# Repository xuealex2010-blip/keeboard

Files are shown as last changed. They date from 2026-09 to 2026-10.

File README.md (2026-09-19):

# Keeboard
Hack Club Sponsored DIY Keyboard

Hey, thanks for checking this out, this is my own attempt at creating a DIY 75% Low Profile Mechanical Keyboard.

More details about the process can be found in the Journal Logs.

## CAD
https://cad.onshape.com/documents/ea891d14d2da634eb3b1d96d/w/6142ce2636ba78c1d8d6bd10/e/d20a11642471013c1442f2cf



I decided to go for an affordable green keycap set since I love the color and its one of the cheapest low profile options.



I used heat set inserts and square nuts to hold the case together, I think that this is better than a large 3D print as its designed to be printed at that size. I used only 2 screw lengths which kept the hardware costs low.

## KiCad
https://kicanvas.org/?repo=https%3A%2F%2Fgithub.com%2Fxuealex2010-blip%2Fkeeboard%2Ftree%2Fmain%2FPCB

### Schematic



The schematic final design uses a very basic layout of all the switches. 
I used a generic connector instead of the PiPico symbol to manage the GPIO positions better. I made sure to double check with the official pinouts.

### PCB



This PCB uses a lot more vias than expected, this was to separate the long traces better, and improve ground fill space.

I also made special edge cuts in the PCB, this is because the low profile layout stabilizers drop deep below the plate that it would collide with the PCB if not so.

## Reflection

This was a fun journey, I learned a lot about keyboards, PCB design, and even some more cad skills in specific use cases.
I wanted to do this project because I thought it would be nice to get a cool mechanical keyboard. This still remains so, but I also realize how much I was able to learn. I also think that the this keyboard is much more than a mechanical keyboard, since it has sentimental value since, well I made it. 
I would like to thank Hack Club for showing me this opportunity, even if I don't get to build it, I have learned a lot.

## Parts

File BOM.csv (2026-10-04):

Vendor | Item | Qty Incl. | Qty Used | Cost (shipping incl) | Link
Aliexpress | Keyswitches | 90 | 82 | $34.15 | https://www.aliexpress.us/item/3256812101477500.html?mp=1&_randl_shipto=US
Aliexpress | Keycaps | 143 | 82 | $19.08 | https://www.aliexpress.us/item/3256804654045406.html?mp=1
Aliexpress | Stabilizers | 5 | 4 | $13.35 | https://www.aliexpress.us/item/3256805109925838.html?mp=1
Aliexpress | EC11 Encoder | 5 | 1 | $2.83 | https://www.aliexpress.us/item/3256801777806102.html?mp=1
Aliexpress | SOD-123 Diode | 500 | 90 | $5.33 | https://www.aliexpress.us/item/3256812429587907.html?curPageLogUid=SeGesrcKaOci
Aliexpress | Pico 2 | 1 | 1 | $2.23 | https://www.aliexpress.us/item/3256805430865417.html?mp=1
Aliexpress | Heat Inserts | 100 | 18 | $2.25 | https://www.aliexpress.us/item/3256807466816961.html?mp=1&_randl_shipto=US
Aliexpress | LP Screws | 40 | 4 | $7.55 | https://www.aliexpress.us/item/3256812814549829.html?mp=1
Aliexpress | CS Screws | 50 | 8 | $3.67 | https://www.aliexpress.us/item/3256805377257558.html?mp=1
Aliexpress | Square Nuts | 40 | 4 | $5.60 | https://www.aliexpress.us/item/3256804067194395.html?mp=1
Aliexpress | Poron Foam | 20 | 8 | $5.74 | https://www.aliexpress.us/item/3256805377257558.html?mp=1
Aliexpress | Rubber Feet | 100 | 4 | $6.03 | https://www.aliexpress.us/item/3256812503581701.html?mp=1
JLCPCB | PCB | 5 | 1 | $36.46

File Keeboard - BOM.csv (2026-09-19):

Item | Qty Incl. | Qty Used
Keyswitches | 90 | 82
Keycaps | 143 | 82
Stabilizers | 5 | 4
EC11 Encoder | 5 | 1
SOD-123 Diode | 500 | 90
Pico 2 | 1 | 1
Heat Inserts | 100 | 18
LP Screws | 40 | 4
CS Screws | 50 | 8
Square Nuts | 40 | 4
Poron Foam | 20 | 8
Rubber Feet | 100 | 4
PCB | 5 | 1

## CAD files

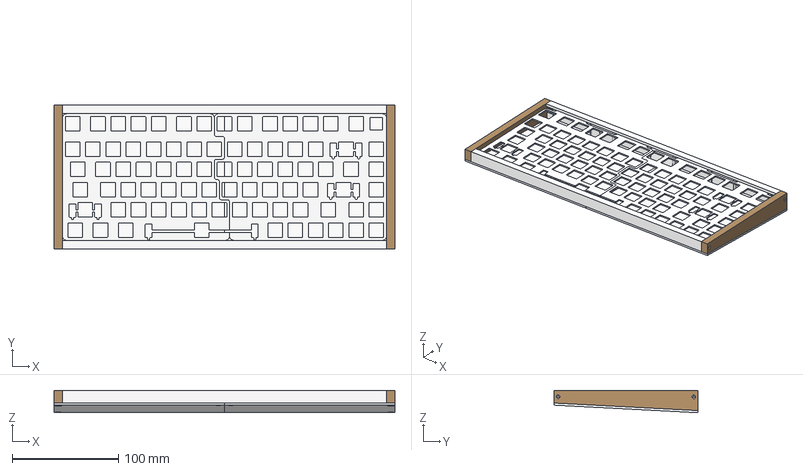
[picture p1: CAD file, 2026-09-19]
3D Print Case/Case Assembly (not for printing).step
320.8 x 135.1 x 21.1 mm
BottomCover-L
Bar S x 2
BottomCover-R
Bar L x 2
Plate-R
Plate-L

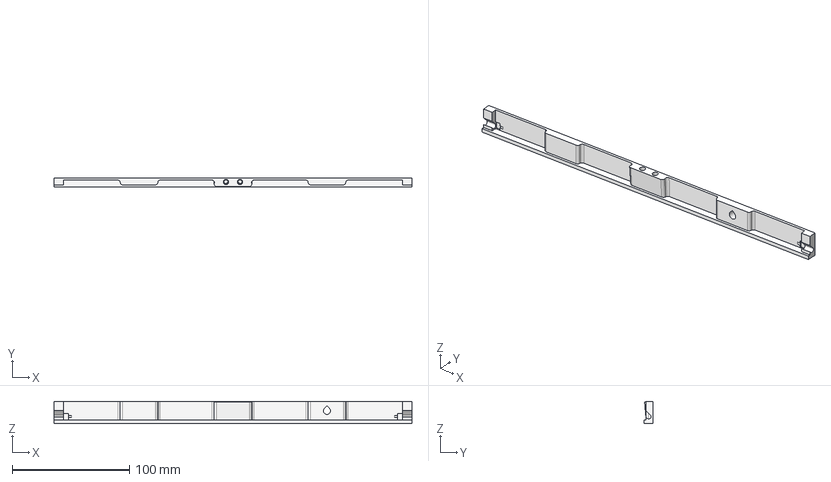
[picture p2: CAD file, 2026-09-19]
3D Print Case/Bar-Back.step
304.8 x 8.00 x 19.0 mm

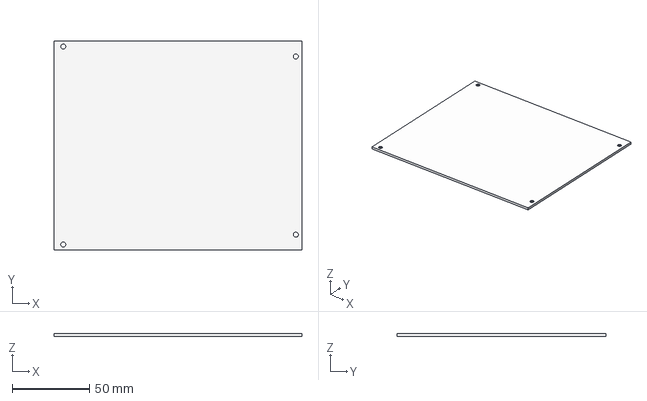
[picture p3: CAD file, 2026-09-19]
3D Print Case/BottomCover-R.step
160.4 x 135.3 x 2.00 mm

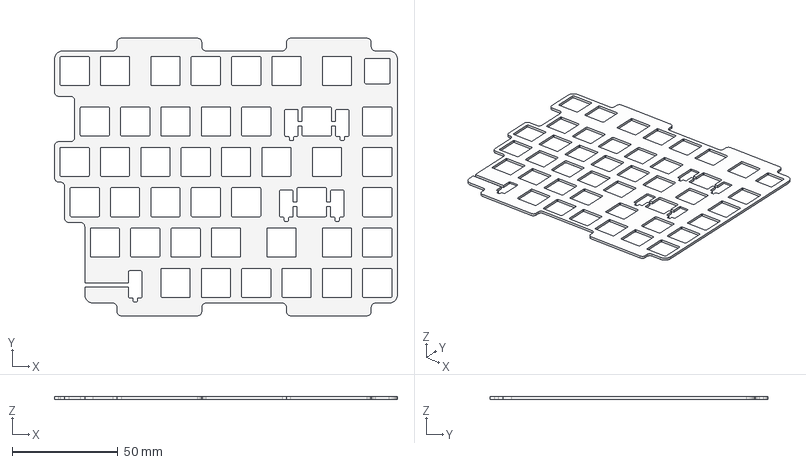
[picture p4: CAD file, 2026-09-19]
3D Print Case/Plate-R.step
161.9 x 131.1 x 1.40 mm

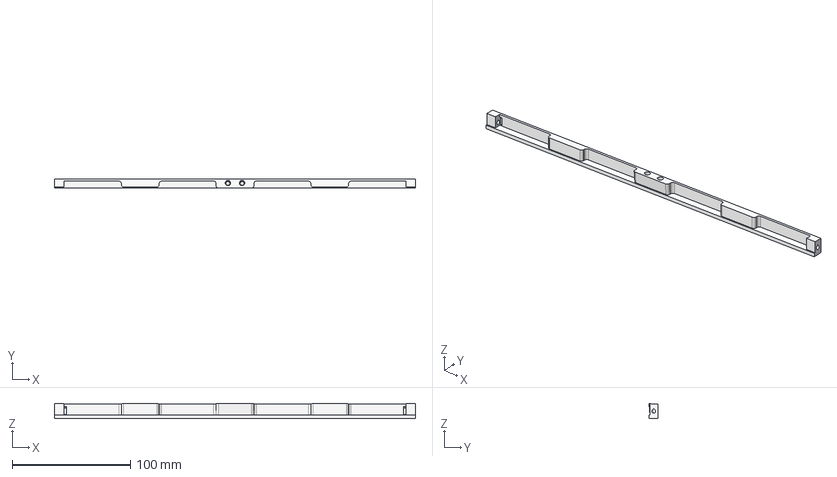
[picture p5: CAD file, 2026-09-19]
3D Print Case/Bar-Front.step
304.8 x 8.00 x 12.4 mm

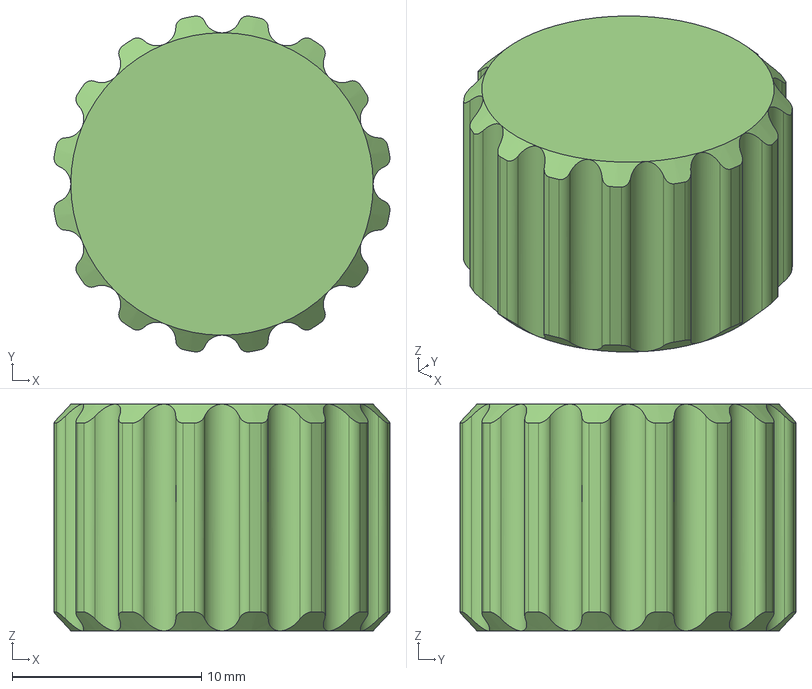
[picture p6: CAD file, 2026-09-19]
3D Print Case/Knob.step
17.8 x 17.8 x 12.0 mm

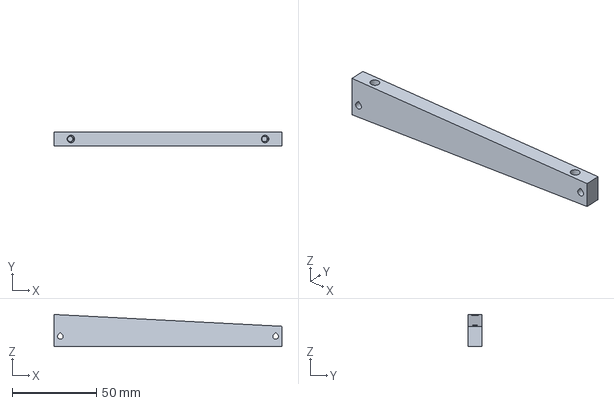
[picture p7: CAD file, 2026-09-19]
3D Print Case/Bar-Sides.step
135.1 x 8.00 x 19.0 mm

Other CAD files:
3D Print Case/BottomCover-L.step
3D Print Case/Plate-L.step

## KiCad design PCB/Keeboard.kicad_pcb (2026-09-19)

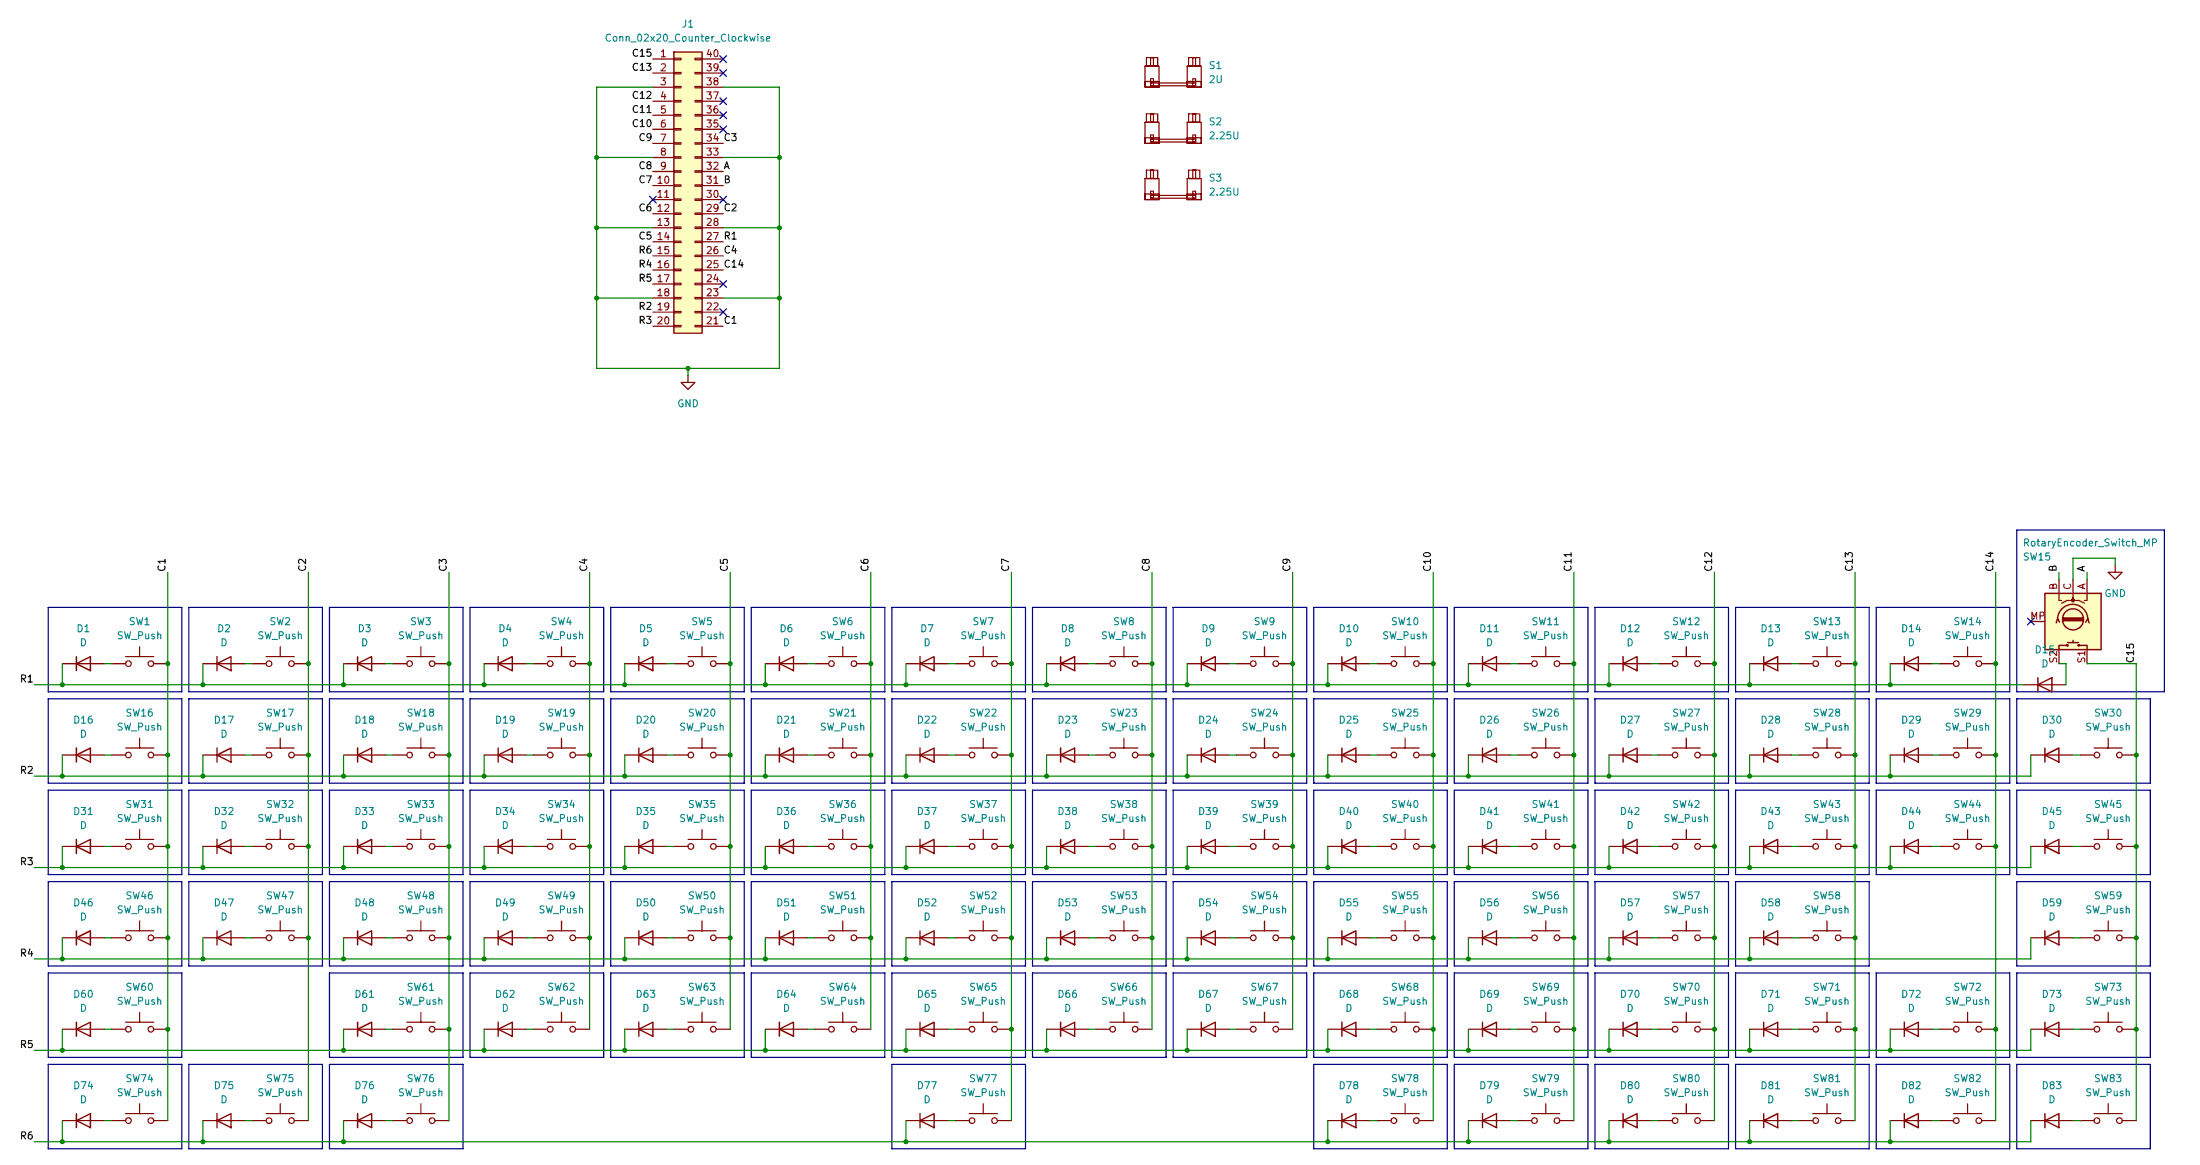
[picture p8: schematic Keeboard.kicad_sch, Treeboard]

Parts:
D1, D2, D3, D4, D5, D6, D7, D8, D9, D10, D11, D12, D13, D14, D15, D16, D17, D18, D19, D20, D21, D22, D23, D24, D25, D26, D27, D28, D29, D30, D31, D32, D33, D34, D35, D36, D37, D38, D39, D40, D41, D42, D43, D44, D45, D46, D47, D48, D49, D50, D51, D52, D53, D54, D55, D56, D57, D58, D59, D60, D61, D62, D63, D64, D65, D66, D67, D68, D69, D70, D71, D72, D73, D74, D75, D76, D77, D78, D79, D80, D81, D82, D83: D; D_SOD-123
J1: Conn_02x20_Counter_Clockwise; RaspberryPi_Pico_Header
S1: 2U; STAB_Combo_2u
S2, S3: 2.25U; STAB_Combo_2.25U
SW1, SW2, SW3, SW4, SW5, SW6, SW7, SW8, SW9, SW10, SW11, SW12, SW13, SW14, SW16, SW17, SW18, SW19, SW20, SW21, SW22, SW23, SW24, SW25, SW26, SW27, SW28, SW29, SW30, SW31, SW32, SW33, SW34, SW35, SW36, SW37, SW38, SW39, SW40, SW41, SW42, SW43, SW44, SW45, SW46, SW47, SW48, SW49, SW50, SW51, SW52, SW53, SW54, SW55, SW56, SW57, SW58, SW59, SW60, SW61, SW62, SW63, SW64, SW65, SW66, SW67, SW68, SW69, SW70, SW71, SW72, SW73, SW74, SW75, SW76, SW77, SW78, SW79, SW80, SW81, SW82, SW83: SW_Push; SW_Combo2_MX_Choc
SW15: RotaryEncoder_Switch_MP; ROT_Alps_EC11E-Switch

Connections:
/A: J1.32, SW15.A
/B: J1.31, SW15.B
/C1: J1.21, SW1.1, SW16.1, SW31.1, SW46.1, SW60.1, SW74.1
/C2: J1.29, SW2.1, SW17.1, SW32.1, SW47.1, SW75.1
/C3: J1.34, SW3.1, SW18.1, SW33.1, SW48.1, SW61.1, SW76.1
/C4: J1.26, SW4.1, SW19.1, SW34.1, SW49.1, SW62.1
/C5: J1.14, SW5.1, SW20.1, SW35.1, SW50.1, SW63.1
/C6: J1.12, SW6.1, SW21.1, SW36.1, SW51.1, SW64.1
/C7: J1.10, SW7.1, SW22.1, SW37.1, SW52.1, SW65.1, SW77.1
/C8: J1.9, SW8.1, SW23.1, SW38.1, SW53.1, SW66.1
/C9: J1.7, SW9.1, SW24.1, SW39.1, SW54.1, SW67.1
/C10: J1.6, SW10.1, SW25.1, SW40.1, SW55.1, SW68.1, SW78.1
/C11: J1.5, SW11.1, SW26.1, SW41.1, SW56.1, SW69.1, SW79.1
/C12: J1.4, SW12.1, SW27.1, SW42.1, SW57.1, SW70.1, SW80.1
/C13: J1.2, SW13.1, SW28.1, SW43.1, SW58.1, SW71.1, SW81.1
/C14: J1.25, SW14.1, SW29.1, SW44.1, SW72.1, SW82.1
/C15: J1.1, SW15.S1, SW30.1, SW45.1, SW59.1, SW73.1, SW83.1
/R1: D1.1 (K), D2.1 (K), D3.1 (K), D4.1 (K), D5.1 (K), D6.1 (K), D7.1 (K), D8.1 (K), D9.1 (K), D10.1 (K), D11.1 (K), D12.1 (K), D13.1 (K), D14.1 (K), D15.1 (K), J1.27
/R2: D16.1 (K), D17.1 (K), D18.1 (K), D19.1 (K), D20.1 (K), D21.1 (K), D22.1 (K), D23.1 (K), D24.1 (K), D25.1 (K), D26.1 (K), D27.1 (K), D28.1 (K), D29.1 (K), D30.1 (K), J1.19
/R3: D31.1 (K), D32.1 (K), D33.1 (K), D34.1 (K), D35.1 (K), D36.1 (K), D37.1 (K), D38.1 (K), D39.1 (K), D40.1 (K), D41.1 (K), D42.1 (K), D43.1 (K), D44.1 (K), D45.1 (K), J1.20
/R4: D46.1 (K), D47.1 (K), D48.1 (K), D49.1 (K), D50.1 (K), D51.1 (K), D52.1 (K), D53.1 (K), D54.1 (K), D55.1 (K), D56.1 (K), D57.1 (K), D58.1 (K), D59.1 (K), J1.16
/R5: D60.1 (K), D61.1 (K), D62.1 (K), D63.1 (K), D64.1 (K), D65.1 (K), D66.1 (K), D67.1 (K), D68.1 (K), D69.1 (K), D70.1 (K), D71.1 (K), D72.1 (K), D73.1 (K), J1.17
/R6: D74.1 (K), D75.1 (K), D76.1 (K), D77.1 (K), D78.1 (K), D79.1 (K), D80.1 (K), D81.1 (K), D82.1 (K), D83.1 (K), J1.15
GND: J1.3, J1.8, J1.13, J1.18, J1.23, J1.28, J1.33, J1.38, SW15.C
unnamed: D1.2 (A), SW1.2
unnamed: D2.2 (A), SW2.2
unnamed: D3.2 (A), SW3.2
unnamed: D4.2 (A), SW4.2
unnamed: D5.2 (A), SW5.2
unnamed: D6.2 (A), SW6.2
unnamed: D7.2 (A), SW7.2
unnamed: D8.2 (A), SW8.2
unnamed: D9.2 (A), SW9.2
unnamed: D10.2 (A), SW10.2
unnamed: D11.2 (A), SW11.2
unnamed: D12.2 (A), SW12.2
unnamed: D13.2 (A), SW13.2
unnamed: D14.2 (A), SW14.2
unnamed: D15.2 (A), SW15.S2
unnamed: D16.2 (A), SW16.2
unnamed: D17.2 (A), SW17.2
unnamed: D18.2 (A), SW18.2
unnamed: D19.2 (A), SW19.2
unnamed: D20.2 (A), SW20.2
unnamed: D21.2 (A), SW21.2
unnamed: D22.2 (A), SW22.2
unnamed: D23.2 (A), SW23.2
unnamed: D24.2 (A), SW24.2
unnamed: D25.2 (A), SW25.2
unnamed: D26.2 (A), SW26.2
unnamed: D27.2 (A), SW27.2
unnamed: D28.2 (A), SW28.2
unnamed: D29.2 (A), SW29.2
unnamed: D30.2 (A), SW30.2
unnamed: D31.2 (A), SW31.2
unnamed: D32.2 (A), SW32.2
unnamed: D33.2 (A), SW33.2
unnamed: D34.2 (A), SW34.2
unnamed: D35.2 (A), SW35.2
unnamed: D36.2 (A), SW36.2
unnamed: D37.2 (A), SW37.2
unnamed: D38.2 (A), SW38.2
unnamed: D39.2 (A), SW39.2
unnamed: D40.2 (A), SW40.2
unnamed: D41.2 (A), SW41.2
unnamed: D42.2 (A), SW42.2
unnamed: D43.2 (A), SW43.2
unnamed: D44.2 (A), SW44.2
unnamed: D45.2 (A), SW45.2
unnamed: D46.2 (A), SW46.2
unnamed: D47.2 (A), SW47.2
unnamed: D48.2 (A), SW48.2
unnamed: D49.2 (A), SW49.2
unnamed: D50.2 (A), SW50.2
unnamed: D51.2 (A), SW51.2
unnamed: D52.2 (A), SW52.2
unnamed: D53.2 (A), SW53.2
unnamed: D54.2 (A), SW54.2
unnamed: D55.2 (A), SW55.2
unnamed: D56.2 (A), SW56.2
unnamed: D57.2 (A), SW57.2
unnamed: D58.2 (A), SW58.2
unnamed: D59.2 (A), SW59.2
unnamed: D60.2 (A), SW60.2
unnamed: D61.2 (A), SW61.2
unnamed: D62.2 (A), SW62.2
unnamed: D63.2 (A), SW63.2
unnamed: D64.2 (A), SW64.2
unnamed: D65.2 (A), SW65.2
unnamed: D66.2 (A), SW66.2
unnamed: D67.2 (A), SW67.2
unnamed: D68.2 (A), SW68.2
unnamed: D69.2 (A), SW69.2
unnamed: D70.2 (A), SW70.2
unnamed: D71.2 (A), SW71.2
unnamed: D72.2 (A), SW72.2
unnamed: D73.2 (A), SW73.2
unnamed: D74.2 (A), SW74.2
unnamed: D75.2 (A), SW75.2
unnamed: D76.2 (A), SW76.2
unnamed: D77.2 (A), SW77.2
unnamed: D78.2 (A), SW78.2
unnamed: D79.2 (A), SW79.2
unnamed: D80.2 (A), SW80.2
unnamed: D81.2 (A), SW81.2
unnamed: D82.2 (A), SW82.2
unnamed: D83.2 (A), SW83.2

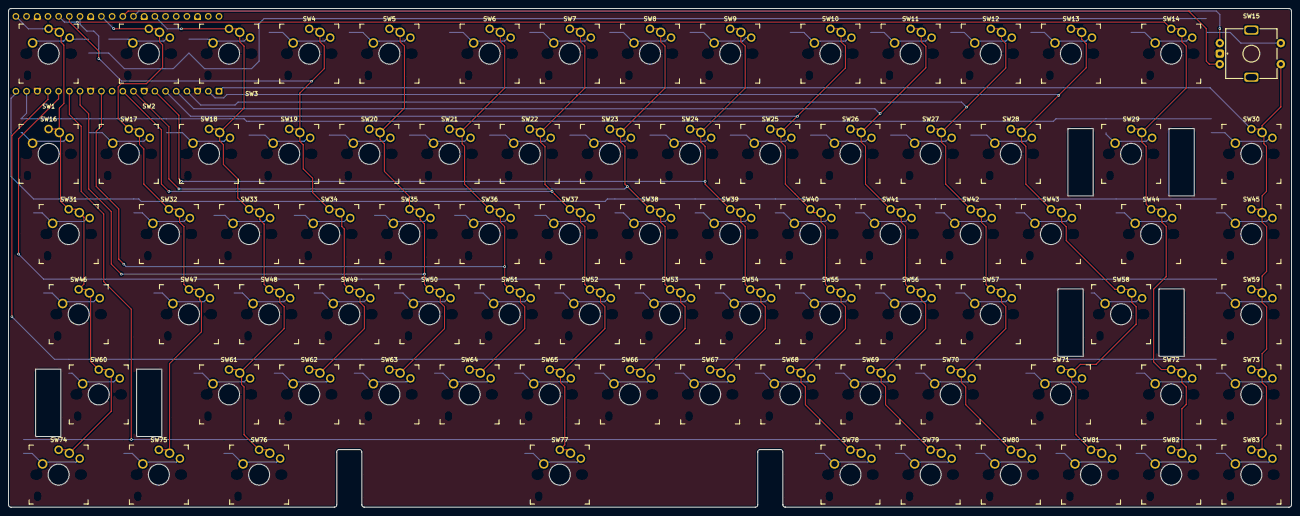
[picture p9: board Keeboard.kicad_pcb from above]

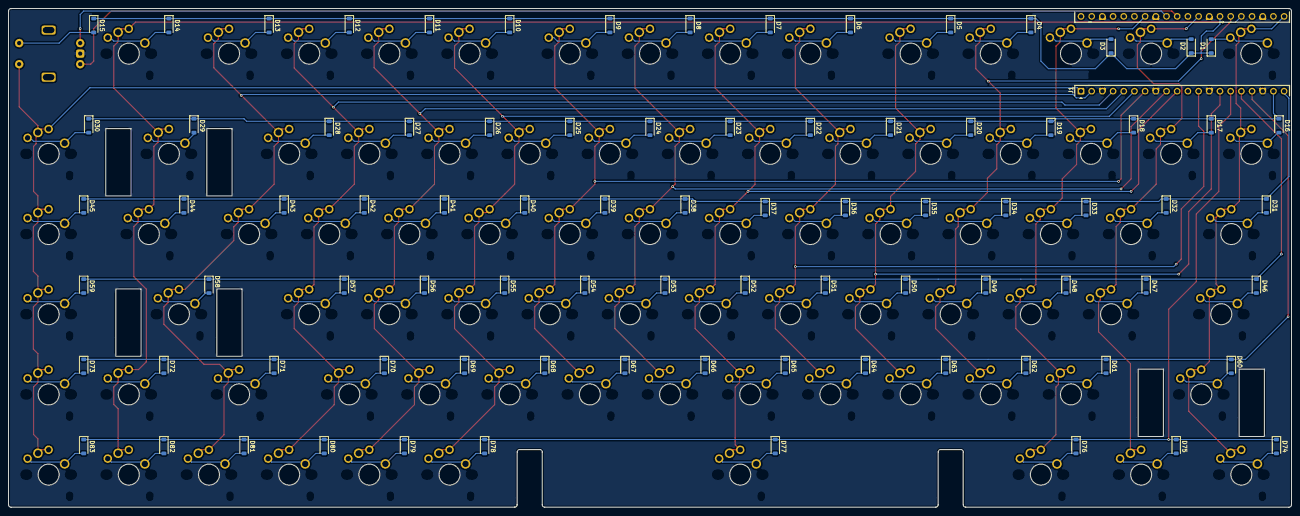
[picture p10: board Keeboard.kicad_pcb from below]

Board: 2 copper layers, 304.8 x 118.5 mm, 170 parts (84 on the bottom side), 107 nets.

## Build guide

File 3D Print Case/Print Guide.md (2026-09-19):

Make sure that the parts are oriented correctly, this should only apply to the bars. 

They should be oriented properly at the start, look for the teardrop shapes, face them upwards to reduce support material.

For big parts, make sure to use a brim to keep bed adhesion, and prevent warping.

These parts have been designed to fit in a 256x256 printing bed. The long bars will need to be rotated 45 degrees to print.

Make sure there are 2 side bars.

#### All of the parts should consist of:

Bar Back

Bar Front

Bar Sides - x2

Bottom Cover Left

Bottom Cover Right

Plate Left

Plate Right

Knob

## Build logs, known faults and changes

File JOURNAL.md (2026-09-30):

---
title: "Treeboard"
author: "Alex"
description: "A 75% mechanical low profile keyboard that I designed"
created_at: "2026-08-19"
---

For transparency, this was created for the YSWS Keeb, but I do not know if I messed up the submission form, and am unsure if I will be able to finish this.

# Journal

### 2026.08.19
First journal entry of the build progress, I have been browsing the web looking for what keyboard I think would be fun to build, as well as the use of rotary encoders. This is a simple log so far, I have only been brainstorming ideas, looking forward to getting able to build it.

Time across all logs:
**Total time spent: 22h**

### 2026.08.20

**Total time spent: 2h**


I spent some time in onshape planning what I would like the layout of my keyboard to be, I like the design of a 75% since it also makes the space for a rotary encoder.
I will have to check the design to make sure it can fit on the pcb!

I learned a bit about different keyboard layouts, like 60% TKL etc. I think that a 75% will be most practical and a good size to make for this project.

### 2026.08.22

**Total time spent: 30m**

Spent some time learning how to use keyboard design generators, this will save me time when I have to port it into CAD software.


I learned about KLE and how to use it, I like using the raw text editing since its just like basic coding. I messed around with certain options that I had.

**Total time spent: 1h 30m**

I decided to commit to the different layout, as the expanded version in my opinion will be more functional, and visually appealing. I now feel ready to begin the PCB design.


### 2026.08.23

**Total time spent: 1h**

Created the schematic for the keyboard, used the work I had done earlier to guide the layout, I decided to try and use a nice nano symbol, as there are many cheap ones on aliexpress.



I learned that I need to pay attention to the diode placement, since it will be important when choosing row2col or col2row scanning.

**Total time spent: 2h**

I worked on the PCB now that I had gotten the rough schematic done, this work was done so that I could check the size and components in cad.
Along with the pcb, I worked on combined footprints to support multiple components in the same spot.



I learned how to use the KiCad footprint editor, I feel pretty good with it now, my first attempt was copy and pasting raw text data to merge 2 footprints, which did not work. But fixing it manually worked.

### 2026.08.29

**Total time spent: 52m**

Took a bit of a while between the last time I worked on this.

I had to reroute the schematic and its diodes so that it properly fits the ROW2COL setup rather than the COL2ROW scanning.
While I was doing so, I decided that I should also implement solder pads in the event that one of the pins was not functioning properly.



### 2026.08.31

**Total time spent: 1h 30m**

Worked on creating the stabilizer mounts, since there are very limited PCB mounted low profile stabilizers, I went with Plate mounted, and had to look through the Gateron datasheets to create a new footprint for the cutouts.

I also took some time to reconsider the layout, but decided that this layout for the 75% was going to be the easiest to work with.

I learned about the different between plate and PCB mounted stabilizers, unfortunately for me, the seemingly better of the 2, PCB mounted, which use actual screws instead of clips, is not readily made in the low profile format.

### 2026.09.01

**Total time spent: 2h**

I decided that the wireless idea was not going to be worth it, since the necessary GPIO pins was too many for the pro micro footprint.

A wireless design while nice, is not very much needed. I will focus my efforts on other aspects.

I remade the PCB and Schematic to now use the Rasberry Pi Pico instead.


Note: Since this is a low profile design, I had to add slots in the PCB, this means that it can NOT support PCB screw in stabilizers. This is unfortunate, but low profile is higher on the priority list.

### 2026.09.05

**Total time spent: 4h**

After overcoming my decision paralysis on what to do. I have decided to commit to using a pi pico as the mcu, this is because it will have all of the gpio pins that I need.
I also decided to change the layout from a fully exploded to only partially, compacting most except the function row. This is because I did not like the look of a cover that would have had to be made in many pieces.


After routing all the traces and resolving most of the errors, it seems that my placement for the pico is not ideal, it has caused some issues with the ground fill and was annoying to route the far sides, I may end up changing it to be more central.

I also made the decision that supporting multiple diode footprints would not be worth it, the tht diodes are much larger and the through hole pads are annoying to deal with for routing.

I learned while routing the traces, it becomes quite compact and tight on space since the switches are rather densely packed. I think there may be some concerns with the ground plane while doing this.

### 2026.09.06

**Total time spent: 2h**

Today I spent some time fiddling with the Pico's placement to optimize the 2 goals I had. Keep the port towards the left region of the board and make traces well routed.

I was able to keep the pico as close to the left as possible, I doubt that moving it towards the center will provide a worthwhile improvement.
I was also able to keep gnd fill between nearly all of the traces.
DRC checker shows 3 errors with the gnd pin connections, but despite this, I believe that they are redundant, and are suitable enough. Though I will check.



Log 2
**Total time spent: 3h**

Got some time this weekend, so I kept going at it.
I exported the PCB and began a prototype case design. To optimize for 3d printing, my goal will be to make the aesthetics work with the maximum sizes.
I also had a mock up for how much of a tilt angle I will need to have on the keyboard to allow clearance for the pico.



### 2026.09.11

**Total time spent: 45m**

Today I used the measurements I took last time to model the actual case. This is a prototype size, but it gives me a sense of how the hardware will fit in place.



### 2026.09.19

**Total time spent: 50m**

Today I finished up the case design. I finalized the bottom cover mounting by using heat set inserts, and made sure that the overhangs were fixed for some of the parts.



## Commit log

2026-09-19 Create Print Guide.md
2026-09-19 Update Print Guide.md
2026-09-30 Rename Keeboard - BOM.csv to BOM.csv
    [BOM.csv]
